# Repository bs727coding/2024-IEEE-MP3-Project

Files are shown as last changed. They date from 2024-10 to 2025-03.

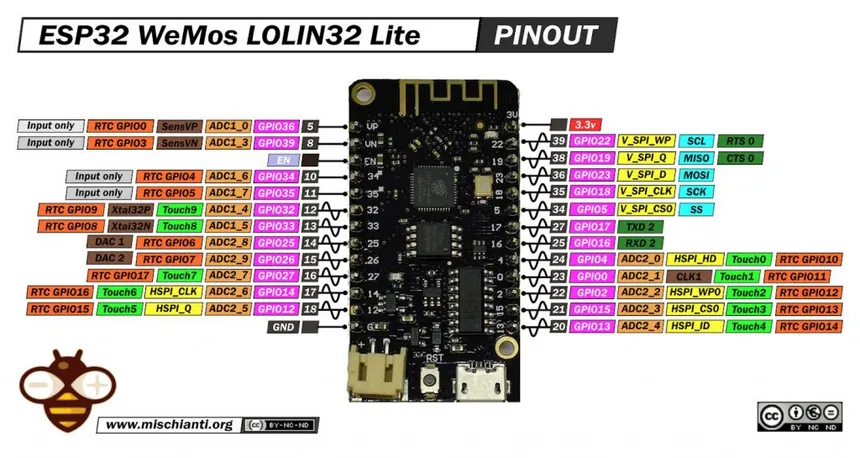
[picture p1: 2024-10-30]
ESP32-WeMos-LOLIN32-Lite-pinout.webp

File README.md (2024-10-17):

# 2024-IEEE-MP3-Project

A simple media player with bluetooth support using an ESP32, LCD display, audio driver, battery, and button controls.

This is a part of the Brigham Young University IEEE student branch 2024-2025 project.

There are 4 outcomes we hope to accomplish with this project. These are:

    Develop an understanding of KiCAD and PCB design, including footprint design, schematic development, and design rules.
    Learn embedded programming by using FreeRTOS and C to program an ESP32 microcontroller to process media files and control its input and output functions.
    Acquire skill in how to use CAD softwares to design an appropriate chassis for electrical components.
    Become confident and consistent in electrical engineering project documentation.

We anticipate this project will be exciting, challenging, and provide participating students an opportunity to grow their engineering skills outside of a classroom setting.

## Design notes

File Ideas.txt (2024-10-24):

What we want to implement:
* designates 1st gen

Sharepoint (cast to Chromecast, Apple airplay, ect.)
*BLDC motor/encoder (selection/volume control)
*SD card (storage)
Emulate USB Mass Storage
*Screen - 2-3 inches, full color
Video?
No internal speaker
Charge circuitry integrated MCU
LiPo or Lion
*IO Buttons: 4
*Single pole triple throw power switch: Off, On, Playback(on but buttons disabled)
Brightness control (possibly via POT and not through ESP32)
Battery indicator (Neopixel)
SOC?
*TRS port (headphone jack, with plugin/unplug detection)

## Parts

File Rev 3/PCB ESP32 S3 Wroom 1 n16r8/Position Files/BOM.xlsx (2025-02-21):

Comment | Designator | Footprint | JLCPCB Part #（optional）
15uh | L1 | Inductor_SMD:L_Vishay_IFSC-1515AH_4x4x1.8mm | C844950
.1uF | C1 | Capacitor_SMD:C_0201_0603Metric | C1591
2.2uF | C2 | Capacitor_SMD:C_0201_0603Metric | C86013
10uf | C3 | Capacitor_SMD:C_0201_0603Metric | C1691
69.8k | R14 | Resistor_SMD:R_01005_0402Metric | C26985
22.1k | R15 | Resistor_SMD:R_01005_0402Metric | C102896
LMR54410DBVR | U1 | LMR54410DBVR:SOT95P280X145-6N | C3200265
ESP 32 S3 Wroom N16R8 | X1 | ESP32-S3-WROOM-1-N16R8 | C2913202

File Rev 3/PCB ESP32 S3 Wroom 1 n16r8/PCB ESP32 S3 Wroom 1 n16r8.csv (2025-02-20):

Id | Designator | Footprint | Quantity | Designation | Supplier and ref
1 | SW1 | Kailh_socket_PG1350 | 1 | Home
2 | J1 | Jack_3.5mm_CUI_SJ1-3524N_Horizontal | 1 | AudioJack3_SwitchT
3 | R4,R1,R2,R3,R6,R5,R13,R8,R11,R9,R10 | R_Axial_DIN0204_L3.6mm_D1.6mm_P7.62mm_Horizontal | 11 | 10K
4 | SW2 | Kailh_socket_PG1350 | 1 | Back
5 | Primary Rotary Encoder1 | RotaryEncoder_Alps_EC11E-Switch_Vertical_H20mm | 1 | RotaryEncoder_Switch
6 | L_SPKR1,RSPKR1 | MAX98357 I2C Audio Driver | 2 | ~
7 | SW5 | Kailh_socket_PG1350 | 1 | Menu
8 | Screen&SDCardReader1 | 2.4'_TFT_SPI_ILI9341_WITH_SD_CARD | 1 | ~
9 | SW3 | Kailh_socket_PG1350 | 1 | Play/Pause
10 | D1 | D_A-405_P7.62mm_Horizontal | 1 | Flyback Diode
11 | M1 | TerminalBlock_RND_205-00001_1x02_P5.00mm_Horizontal | 1 | Haptic Feedback
12 | R12 | R_Axial_DIN0204_L3.6mm_D1.6mm_P7.62mm_Horizontal | 1 | 100K
13 | C1 | C_0201_0603Metric | 1 | .1 uF
14 | SW6 | SW_Slide_SPDT_Angled_CK_OS102011MA1Q | 1 | Hold
15 | L1 | L_Vishay_IFSC-1515AH_4x4x1.8mm | 1 | 15uH
16 | X1 | ESP32S3WROOM1N8R2 | 1 | ESP32-S3-WROOM-1-N16R8
17 | SW4 | SW_Slide_SPDT_Angled_CK_OS102011MA1Q | 1 | Power
18 | R14 | R_01005_0402Metric | 1 | 69.8K
19 | SW7 | SW_PUSH_6mm | 1 | BOOT_MODE
20 | C3 | C_0201_0603Metric | 1 | 10uF
21 | Q1 | TO-92_Inline | 1 | BS170
22 | C2 | C_0201_0603Metric | 1 | 2.2 uF
23 | U1 | SOT95P280X145-6N | 1 | LMR54410DBVR
24 | R7 | R_Axial_DIN0204_L3.6mm_D1.6mm_P7.62mm_Horizontal | 1 | 0-100Ω
25 | R15 | R_01005_0402Metric | 1 | 22.1K
26 | 1 | UART_FTDI | 1 | ~

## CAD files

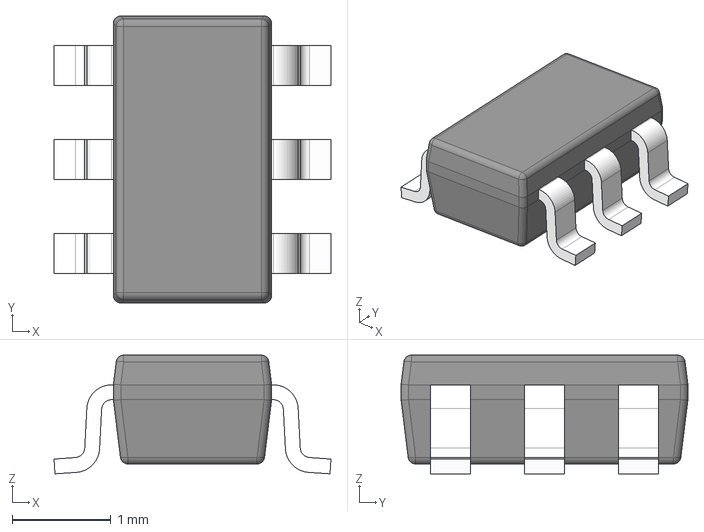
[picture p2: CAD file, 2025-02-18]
Rev 3/PCB ESP32 S3 Wroom 1 n16r8/LMR54410DBVR/LMR54410DBVR.stp
2.80 x 2.90 x 1.20 mm
BODY-SOT
LEAD-SOT x 6

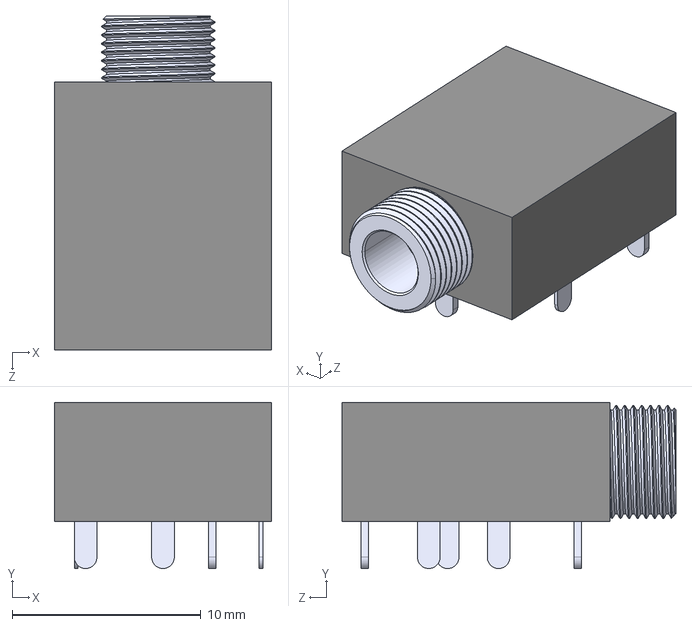
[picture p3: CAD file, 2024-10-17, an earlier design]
Rev 1/Custom Footprints/PJ324M/PJ324M.step
11.5 x 8.80 x 17.7 mm

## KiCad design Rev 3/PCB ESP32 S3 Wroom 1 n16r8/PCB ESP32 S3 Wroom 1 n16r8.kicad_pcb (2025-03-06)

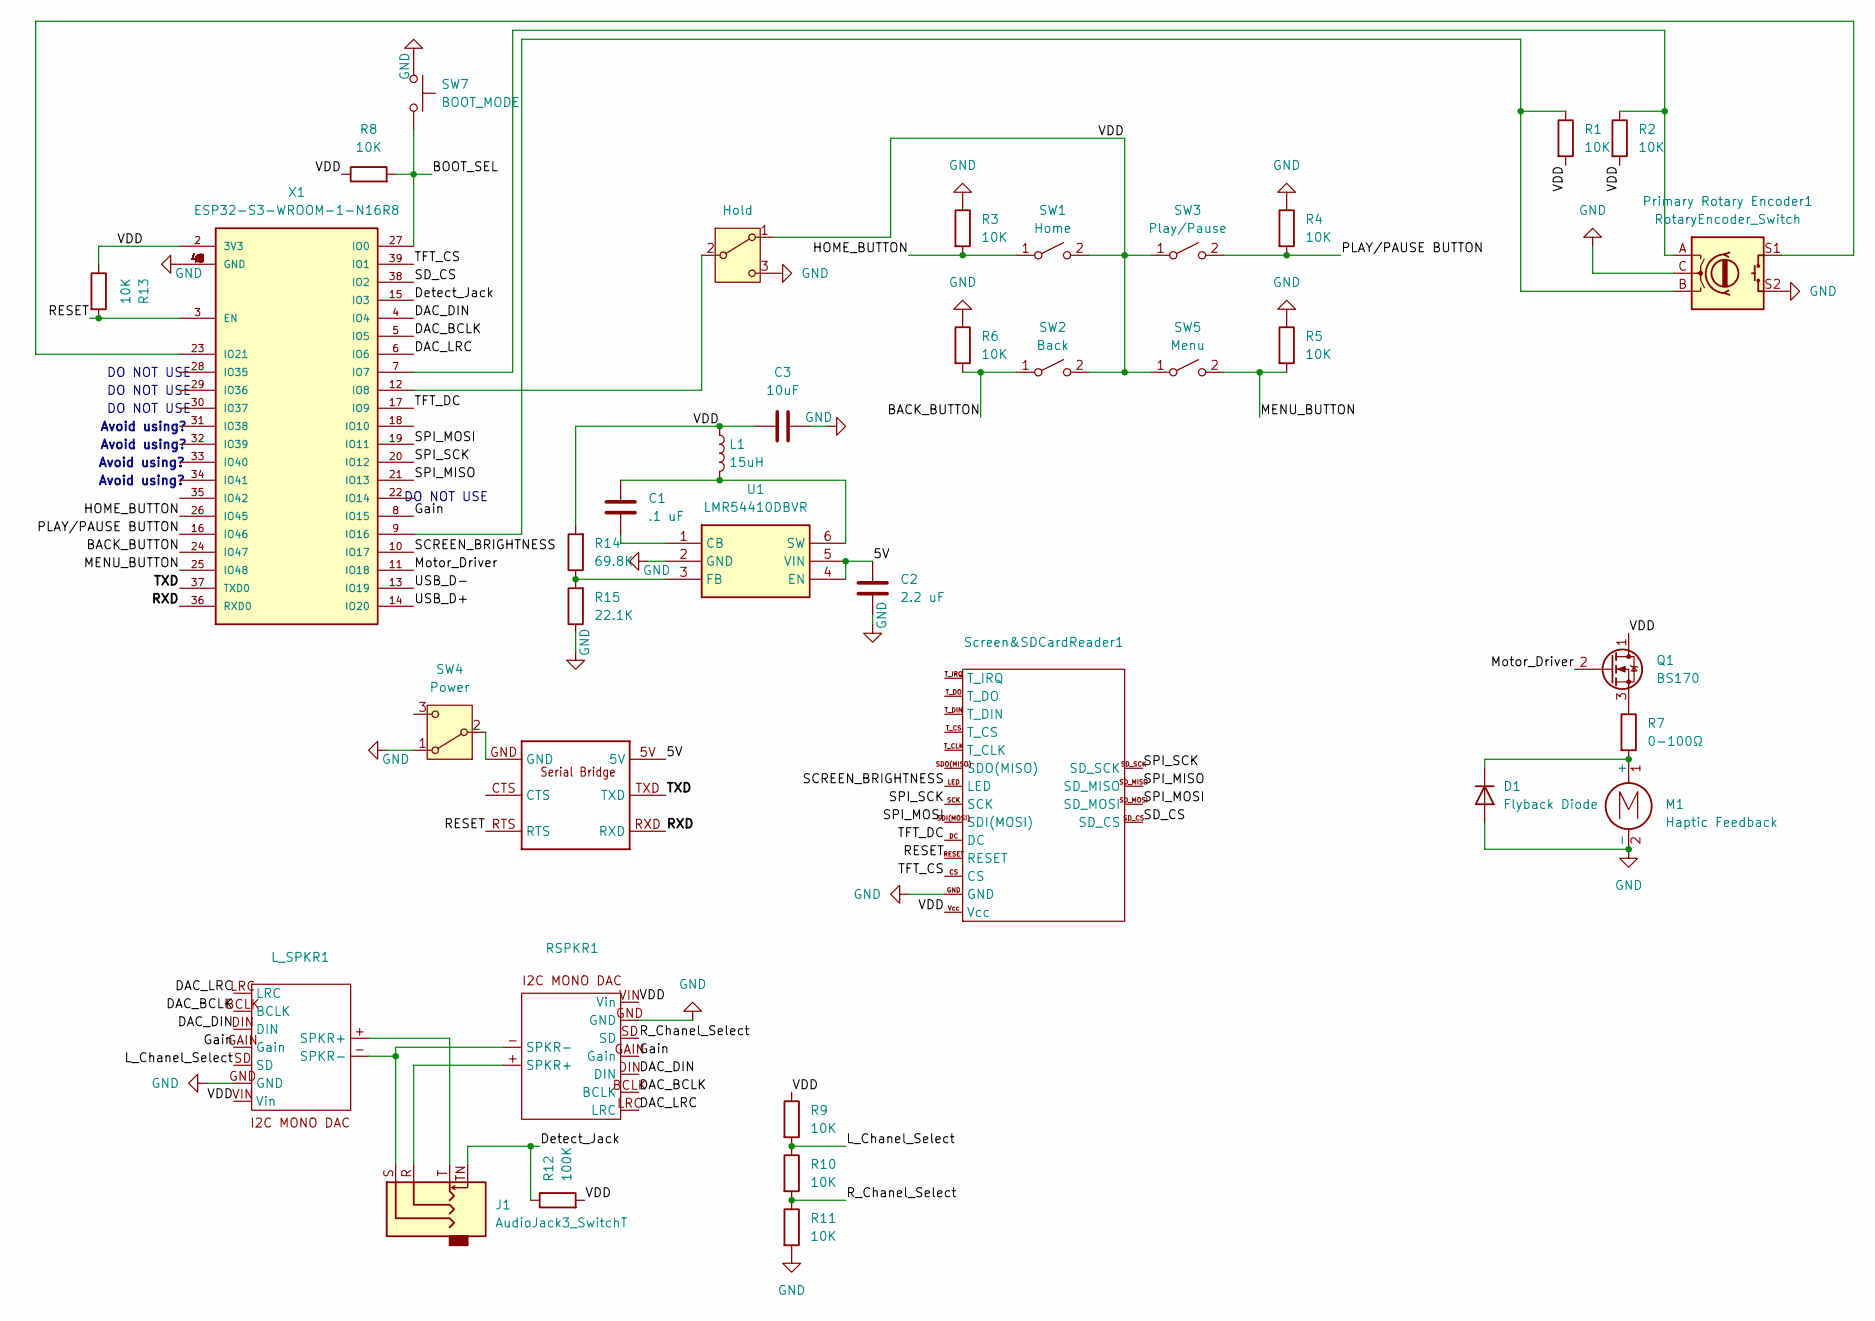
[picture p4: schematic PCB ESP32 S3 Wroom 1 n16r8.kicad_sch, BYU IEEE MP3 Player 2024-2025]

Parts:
1: UART_FTDI
C1: .1 uF; C_0603_1608Metric
C2: 2.2 uF; C_0603_1608Metric
C3: 10uF; C_0603_1608Metric
D1: Flyback Diode; D_A-405_P7.62mm_Horizontal
J1: AudioJack3_SwitchT; Jack_3.5mm_CUI_SJ1-3524N_Horizontal
L1: 15uH; L_Vishay_IFSC-1515AH_4x4x1.8mm
L_SPKR1: MAX98357 I2C Audio Driver
M1: Haptic Feedback; TerminalBlock_RND_205-00001_1x02_P5.00mm_Horizontal
Primary Rotary Encoder1: RotaryEncoder_Switch; RotaryEncoder_Alps_EC11E-Switch_Vertical_H20mm
Q1: BS170; TO-92_Inline
R1, R2, R3, R4, R5, R6, R8, R9, R10, R11, R13: 10K; R_Axial_DIN0204_L3.6mm_D1.6mm_P7.62mm_Horizontal
R7: 0-100Ω; R_Axial_DIN0204_L3.6mm_D1.6mm_P7.62mm_Horizontal
R12: 100K; R_Axial_DIN0204_L3.6mm_D1.6mm_P7.62mm_Horizontal
R14: 69.8K; R_01005_0402Metric_Pad0.57x0.30mm_HandSolder
R15: 22.1K; R_01005_0402Metric_Pad0.57x0.30mm_HandSolder
RSPKR1: MAX98357 I2C Audio Driver
SW1: Home; Kailh_socket_PG1350
SW2: Back; Kailh_socket_PG1350
SW3: Play/Pause; Kailh_socket_PG1350
SW4: Power; SW_Slide_SPDT_Angled_CK_OS102011MA1Q
SW5: Menu; Kailh_socket_PG1350
SW6: Hold; SW_Slide_SPDT_Angled_CK_OS102011MA1Q
SW7: BOOT_MODE; SW_PUSH_6mm
Screen&SDCardReader1: 2.4'_TFT_SPI_ILI9341_WITH_SD_CARD
U1: LMR54410DBVR; SOT95P280X145-6N; Mouser Part Number 595-LMR54410DBVR
X1: ESP32-S3-WROOM-1-N16R8; ESP32S3WROOM1N8R2; MANUFACTURER_PART_NUMBER ESP32-S3-WROOM-1-N16R8

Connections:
/5V: 1.5V, C2.2, U1.4 (EN), U1.5 (VIN)
/BACK_BUTTON: R6.2, SW2.1 (A), X1.24 (IO47)
/BOOT_SEL: R8.2, SW7.2, X1.27 (IO0)
/DAC_BCLK: L_SPKR1.BCLK, RSPKR1.BCLK, X1.5 (IO5)
/DAC_DIN: L_SPKR1.DIN, RSPKR1.DIN, X1.4 (IO4)
/DAC_LRC: L_SPKR1.LRC, RSPKR1.LRC, X1.6 (IO6)
/Detect_Jack: J1.TN, R12.1, X1.15 (IO3)
/Gain: L_SPKR1.GAIN (Gain), RSPKR1.GAIN (Gain), X1.8 (IO15)
/HOME_BUTTON: R3.2, SW1.1 (A), X1.26 (IO45)
/L_Chanel_Select: L_SPKR1.SD, R9.2, R10.1
/MENU_BUTTON: R5.2, SW5.2 (B), X1.25 (IO48)
/Motor_Driver: Q1.2 (G), X1.11 (IO18)
/PLAY/PAUSE BUTTON: R4.2, SW3.2 (B), X1.16 (IO46)
/RESET: 1.RTS, R13.2, Screen&SDCardReader1.RESET, X1.3 (EN)
/RXD: 1.RXD, X1.36 (RXD0)
/R_Chanel_Select: R10.2, R11.1, RSPKR1.SD
/SCREEN_BRIGHTNESS: Screen&SDCardReader1.LED, X1.10 (IO17)
/SD_CS: Screen&SDCardReader1.SD_CS, X1.38 (IO2)
/SPI_MISO: Screen&SDCardReader1.SD_MISO, X1.21 (IO13)
/SPI_MOSI: Screen&SDCardReader1.SDI(MOSI), Screen&SDCardReader1.SD_MOSI, X1.19 (IO11)
/SPI_SCK: Screen&SDCardReader1.SCK, Screen&SDCardReader1.SD_SCK, X1.20 (IO12)
/TFT_CS: Screen&SDCardReader1.CS, X1.39 (IO1)
/TFT_DC: Screen&SDCardReader1.DC, X1.17 (IO9)
/TXD: 1.TXD, X1.37 (TXD0)
/USB_D+: X1.14 (IO20)
/USB_D-: X1.13 (IO19)
/VDD: C3.2, L1.1, L_SPKR1.VIN (Vin), Q1.1 (D), R1.2, R2.2, R8.1, R9.1, R12.2, R13.1, R14.2, RSPKR1.VIN (Vin), SW1.2 (B), SW2.2 (B), SW3.1 (A), SW5.1 (A), SW6.1 (A), Screen&SDCardReader1.Vcc, X1.2 (3V3)
GND: C2.1, C3.1, D1.2 (A), L_SPKR1.GND, M1.2 (-), Primary Rotary Encoder1.C, Primary Rotary Encoder1.S2, R3.1, R4.1, R5.1, R6.1, R11.2, R15.1, RSPKR1.GND, SW4.1 (A), SW6.3 (C), SW7.1, Screen&SDCardReader1.GND, U1.2 (GND), X1.1 (GND), X1.40 (GND), X1.41 (GND), X1.42 (GND), X1.43 (GND), X1.44 (GND), X1.45 (GND), X1.46 (GND), X1.47 (GND), X1.48 (GND), X1.49 (GND)
unnamed: D1.1 (K), M1.1 (+), R7.2
unnamed: J1.T, L_SPKR1.+ (SPKR+)
unnamed: J1.S, L_SPKR1.- (SPKR-), RSPKR1.- (SPKR-)
unnamed: Q1.3 (S), R7.1
unnamed: J1.R, RSPKR1.+ (SPKR+)
unnamed: 1.GND, SW4.2 (B)
unnamed: SW6.2 (B), X1.12 (IO8)
unnamed: C1.2, U1.1 (CB)
unnamed: R14.1, R15.2, U1.3 (FB)
unnamed: C1.1, L1.2, U1.6 (SW)
unnamed: Primary Rotary Encoder1.A, R2.1, X1.7 (IO7)
unnamed: Primary Rotary Encoder1.B, R1.1, X1.9 (IO16)
unnamed: Primary Rotary Encoder1.S1, X1.23 (IO21)

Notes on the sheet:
Avoid using?
DO NOT USE

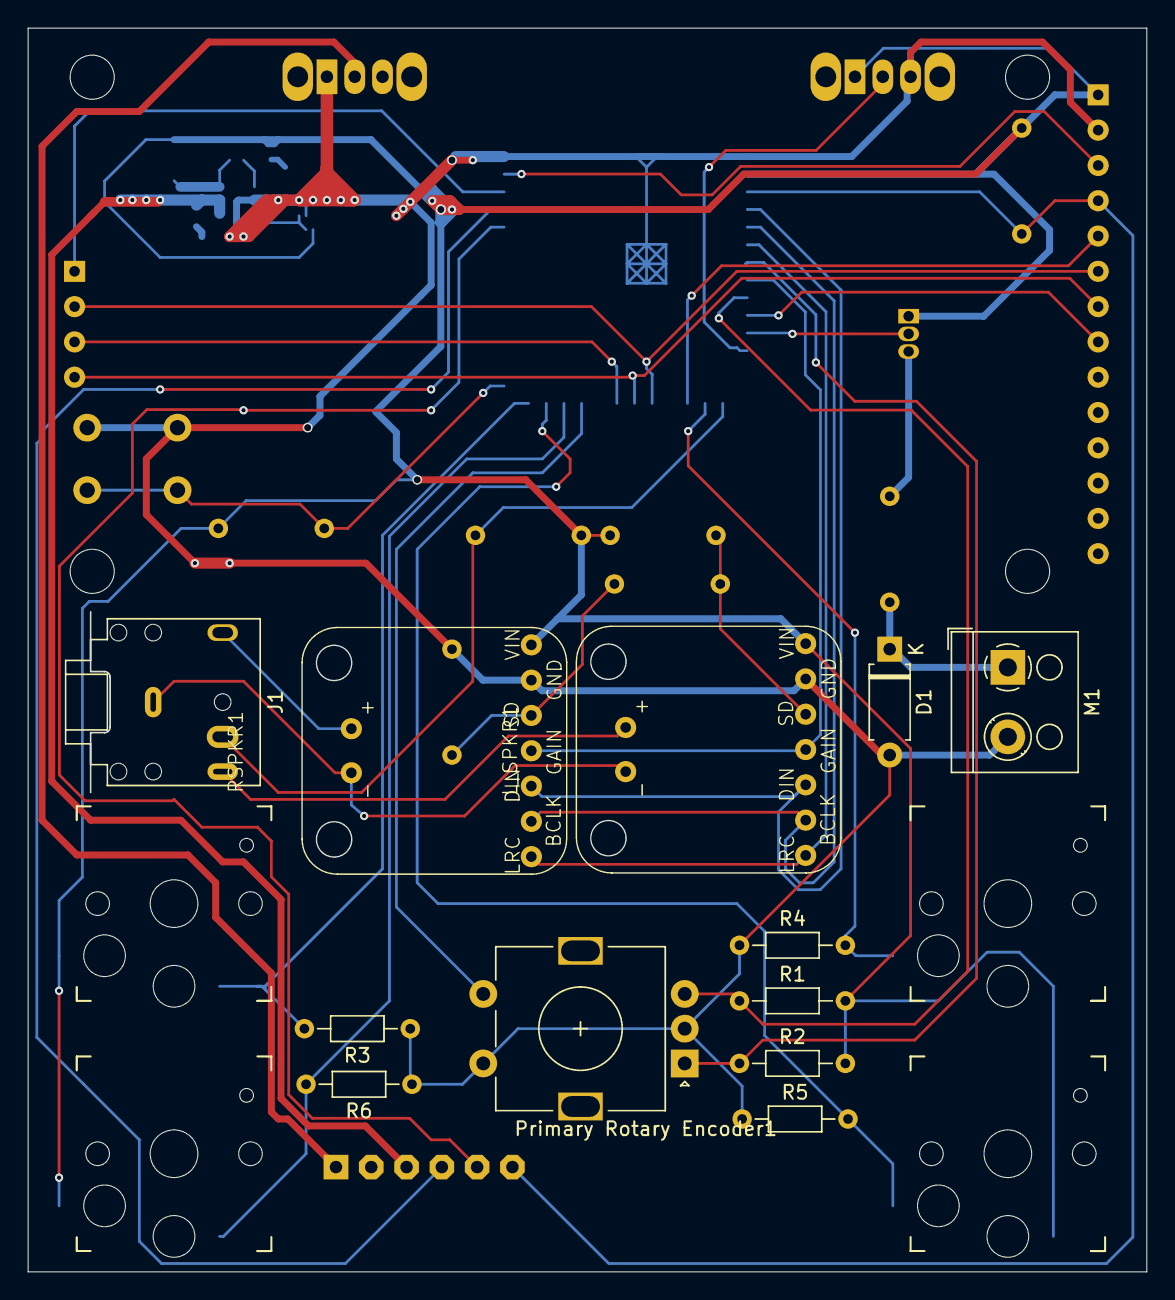
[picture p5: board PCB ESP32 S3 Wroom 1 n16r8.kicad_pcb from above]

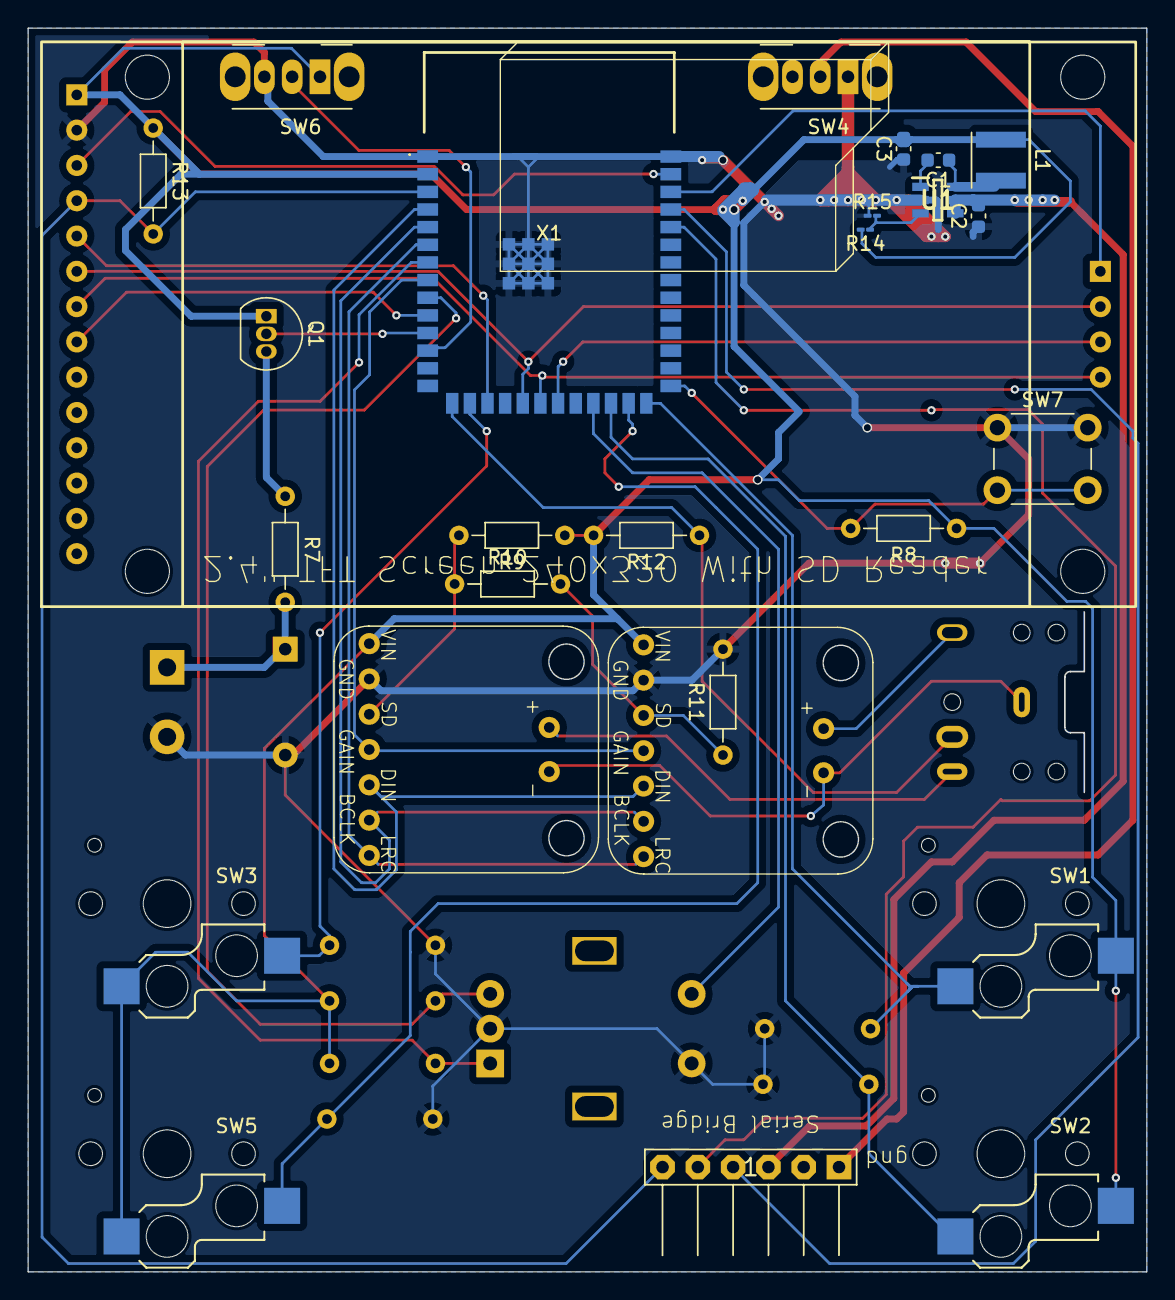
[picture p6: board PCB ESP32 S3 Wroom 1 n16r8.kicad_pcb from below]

Board: 2 copper layers, 80.5 x 89.5 mm, 37 parts (20 on the bottom side), 39 nets.

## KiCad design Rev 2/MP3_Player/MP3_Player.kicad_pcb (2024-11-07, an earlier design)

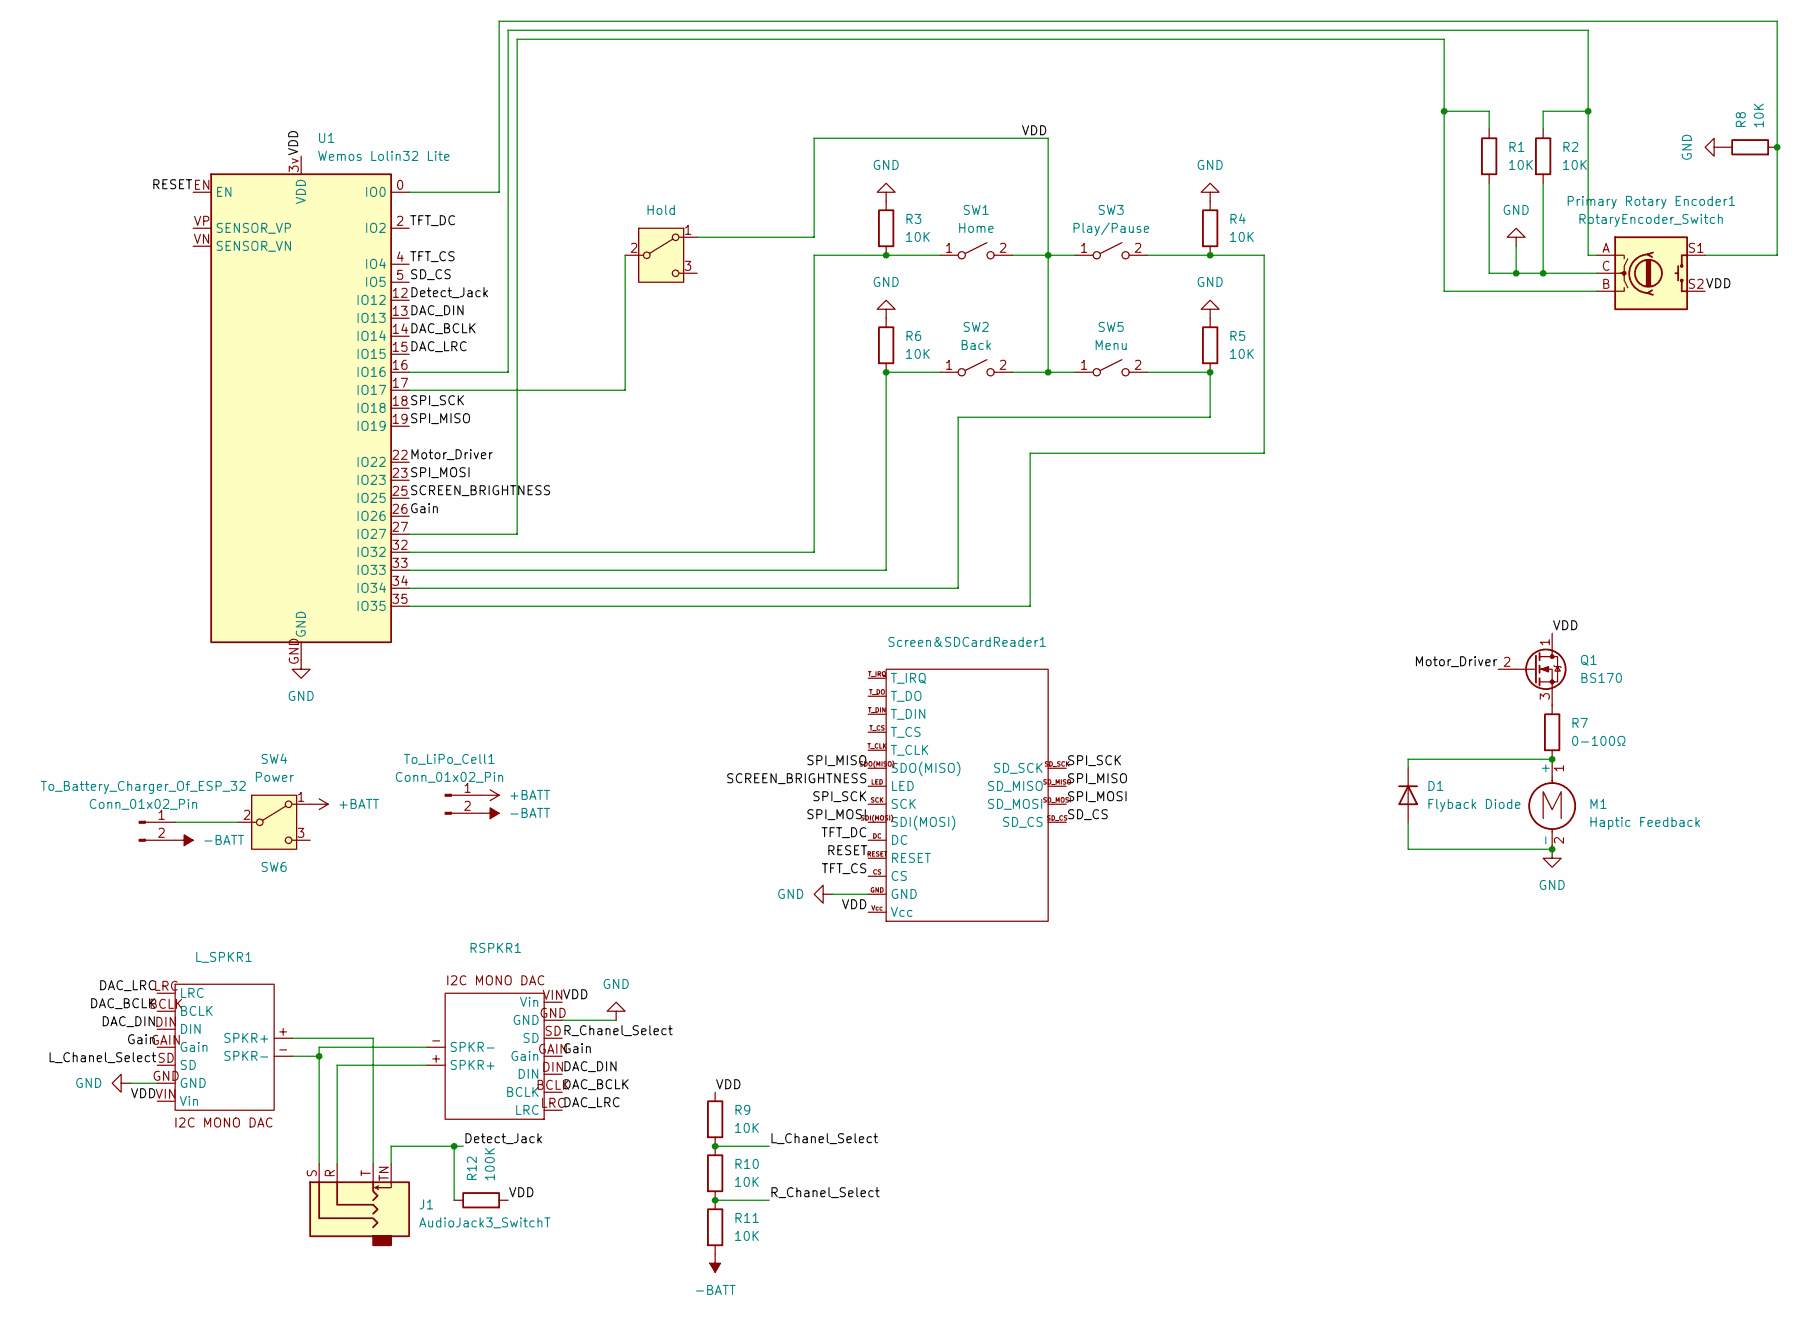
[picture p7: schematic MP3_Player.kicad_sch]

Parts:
D1: Flyback Diode; D_A-405_P7.62mm_Horizontal
J1: AudioJack3_SwitchT; Jack_3.5mm_CUI_SJ1-3524N_Horizontal
L_SPKR1: MAX98357 I2C Audio Driver
M1: Haptic Feedback; TerminalBlock_RND_205-00001_1x02_P5.00mm_Horizontal
Primary Rotary Encoder1: RotaryEncoder_Switch; RotaryEncoder_Alps_EC11E-Switch_Vertical_H20mm
Q1: BS170; TO-92_Inline
R1, R2, R3, R4, R5, R6, R8, R9, R10, R11: 10K; R_Axial_DIN0204_L3.6mm_D1.6mm_P7.62mm_Horizontal
R7: 0-100Ω; R_Axial_DIN0204_L3.6mm_D1.6mm_P7.62mm_Horizontal
R12: 100K; R_Axial_DIN0204_L3.6mm_D1.6mm_P7.62mm_Horizontal
RSPKR1: MAX98357 I2C Audio Driver
SW1: Home; Kailh_socket_PG1350
SW2: Back; Kailh_socket_PG1350
SW3: Play/Pause; Kailh_socket_PG1350
SW4: Power; SW_Slide_SPDT_Angled_CK_OS102011MA1Q
SW5: Menu; Kailh_socket_PG1350
SW6: Hold; SW_Slide_SPDT_Angled_CK_OS102011MA1Q
Screen&SDCardReader1: 2.4'_TFT_SPI_ILI9341_WITH_SD_CARD
To_Battery_Charger_Of_ESP_32: Conn_01x02_Pin; JST_XA_B02B-XASK-1-A_1x02_P2.50mm_Vertical
To_LiPo_Cell1: Conn_01x02_Pin; JST_XA_B02B-XASK-1-A_1x02_P2.50mm_Vertical
U1: Wemos Lolin32 Lite; Wemos Lolin32 Lite v1.0.0

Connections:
+BATT: SW4.1 (A), To_LiPo_Cell1.1
-BATT: R11.2, To_Battery_Charger_Of_ESP_32.2, To_LiPo_Cell1.2
/DAC_BCLK: L_SPKR1.BCLK, RSPKR1.BCLK, U1.14 (IO14)
/DAC_DIN: L_SPKR1.DIN, RSPKR1.DIN, U1.13 (IO13)
/DAC_LRC: L_SPKR1.LRC, RSPKR1.LRC, U1.15 (IO15)
/Detect_Jack: J1.TN, R12.1, U1.12 (IO12)
/Gain: L_SPKR1.GAIN (Gain), RSPKR1.GAIN (Gain), U1.26 (IO26)
/L_Chanel_Select: L_SPKR1.SD, R9.2, R10.1
/Motor_Driver: Q1.2 (G), U1.22 (IO22)
/RESET: Screen&SDCardReader1.RESET, U1.EN
/R_Chanel_Select: R10.2, R11.1, RSPKR1.SD
/SCREEN_BRIGHTNESS: Screen&SDCardReader1.LED, U1.25 (IO25)
/SD_CS: Screen&SDCardReader1.SD_CS, U1.5 (IO5)
/SPI_MISO: Screen&SDCardReader1.SDO(MISO), Screen&SDCardReader1.SD_MISO, U1.19 (IO19)
/SPI_MOSI: Screen&SDCardReader1.SDI(MOSI), Screen&SDCardReader1.SD_MOSI, U1.23 (IO23)
/SPI_SCK: Screen&SDCardReader1.SCK, Screen&SDCardReader1.SD_SCK, U1.18 (IO18)
/TFT_CS: Screen&SDCardReader1.CS, U1.4 (IO4)
/TFT_DC: Screen&SDCardReader1.DC, U1.2 (IO2)
/VDD: L_SPKR1.VIN (Vin), Primary Rotary Encoder1.S2, Q1.1 (D), R9.1, R12.2, RSPKR1.VIN (Vin), SW1.2 (B), SW2.2 (B), SW3.1 (A), SW5.1 (A), SW6.1 (A), Screen&SDCardReader1.Vcc, U1.3v (VDD)
GND: D1.2 (A), L_SPKR1.GND, M1.2 (-), Primary Rotary Encoder1.C, R1.2, R2.2, R3.1, R4.1, R5.1, R6.1, R8.1, RSPKR1.GND, Screen&SDCardReader1.GND, U1.GND
unnamed: D1.1 (K), M1.1 (+), R7.2
unnamed: J1.T, L_SPKR1.+ (SPKR+)
unnamed: J1.S, L_SPKR1.- (SPKR-), RSPKR1.- (SPKR-)
unnamed: Q1.3 (S), R7.1
unnamed: J1.R, RSPKR1.+ (SPKR+)
unnamed: R3.2, SW1.1 (A), U1.32 (IO32)
unnamed: R6.2, SW2.1 (A), U1.33 (IO33)
unnamed: R4.2, SW3.2 (B), U1.35 (IO35)
unnamed: SW4.2 (B), To_Battery_Charger_Of_ESP_32.1
unnamed: R5.2, SW5.2 (B), U1.34 (IO34)
unnamed: SW6.2 (B), U1.17 (IO17)
unnamed: Primary Rotary Encoder1.S1, R8.2, U1.0 (IO0)
unnamed: Primary Rotary Encoder1.A, R2.1, U1.16 (IO16)
unnamed: Primary Rotary Encoder1.B, R1.1, U1.27 (IO27)

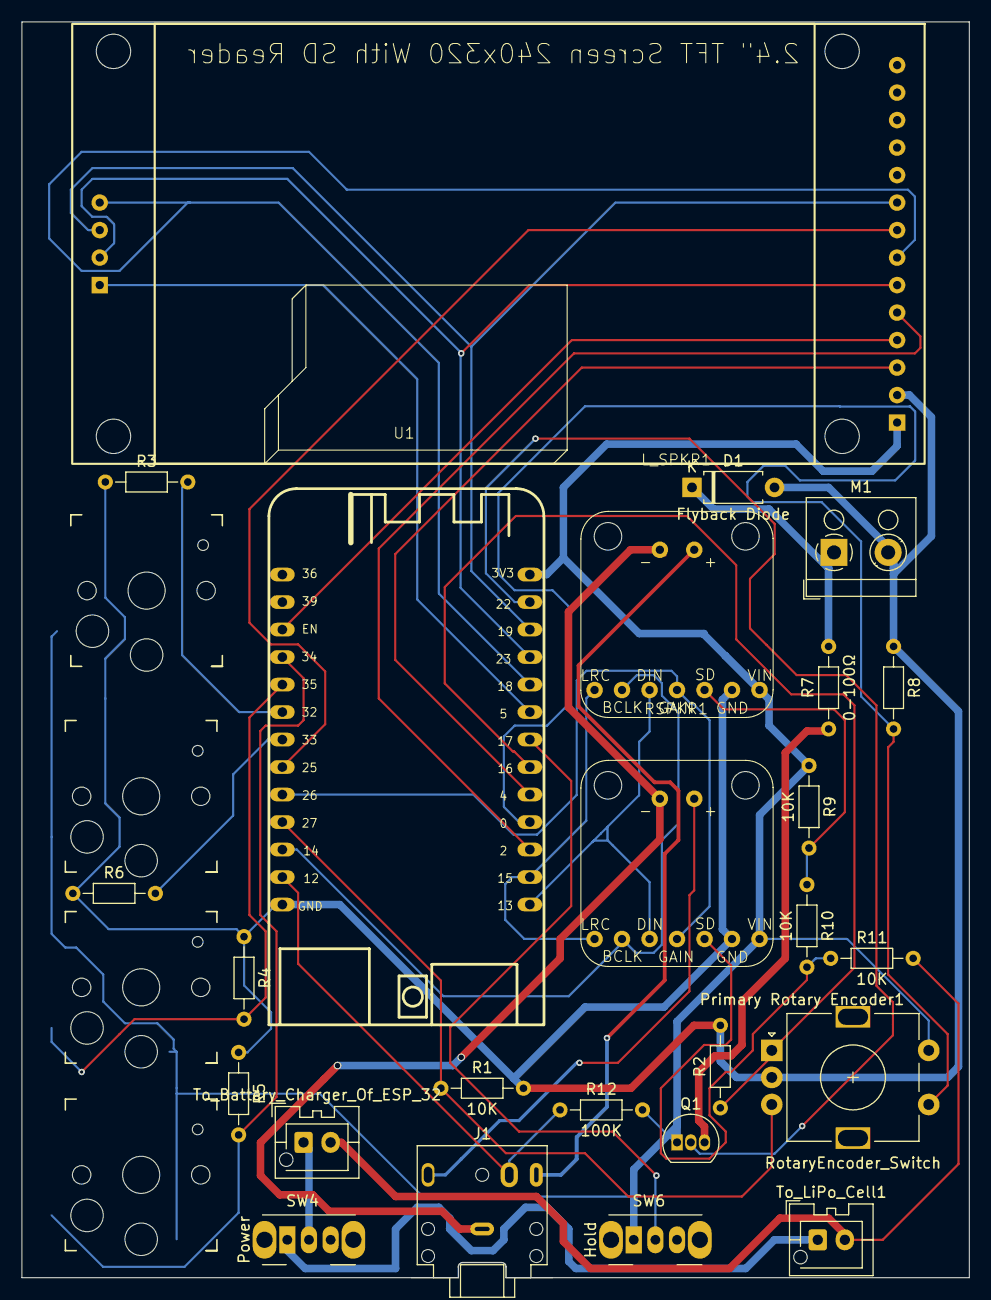
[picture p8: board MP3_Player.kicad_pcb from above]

Board: 2 copper layers, 87.5 x 116.0 mm, 29 parts (1 on the bottom side), 34 nets.

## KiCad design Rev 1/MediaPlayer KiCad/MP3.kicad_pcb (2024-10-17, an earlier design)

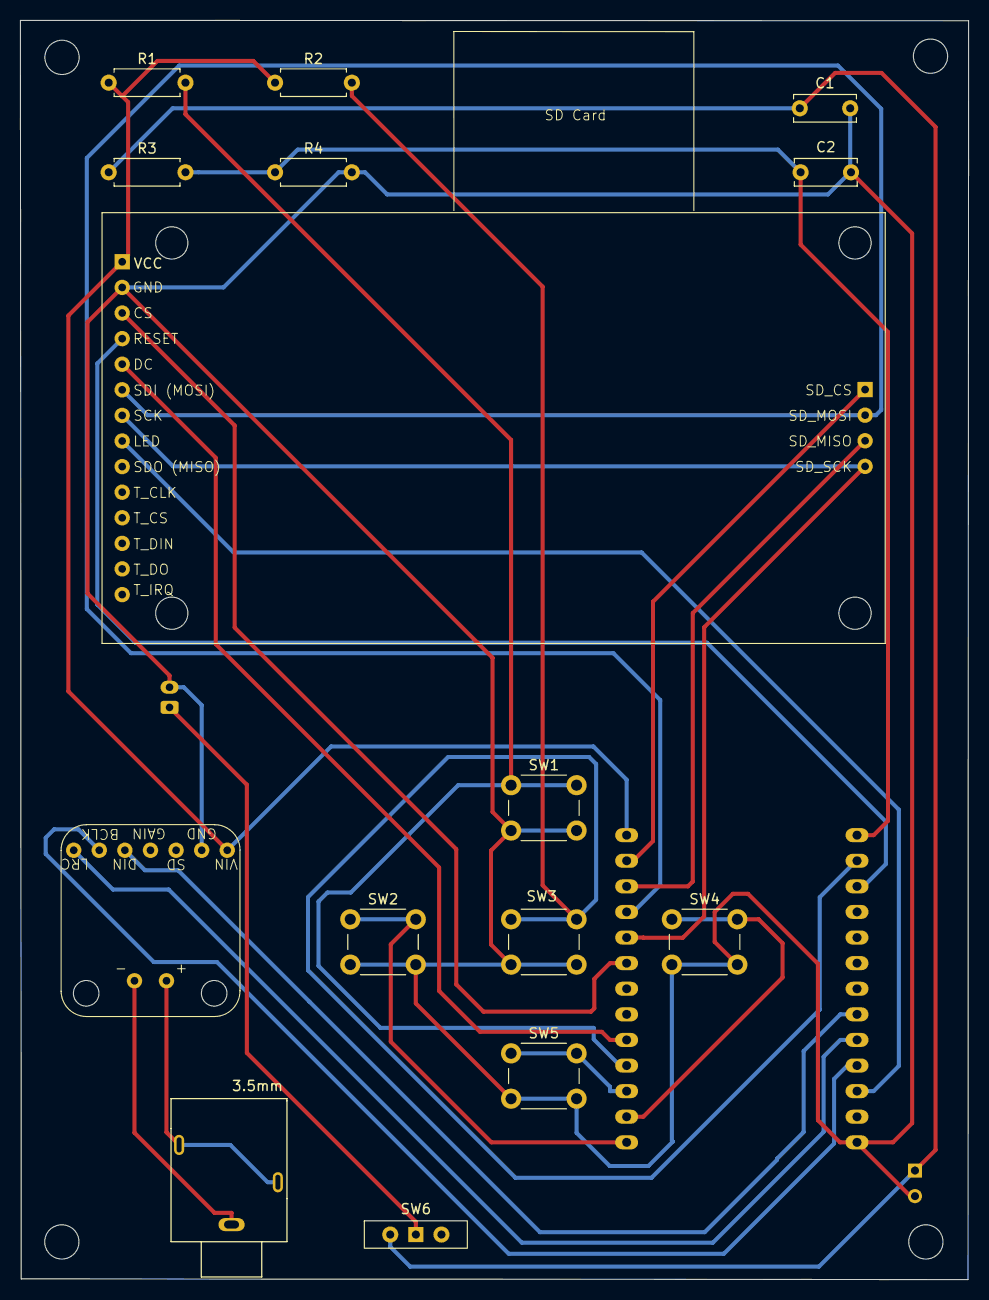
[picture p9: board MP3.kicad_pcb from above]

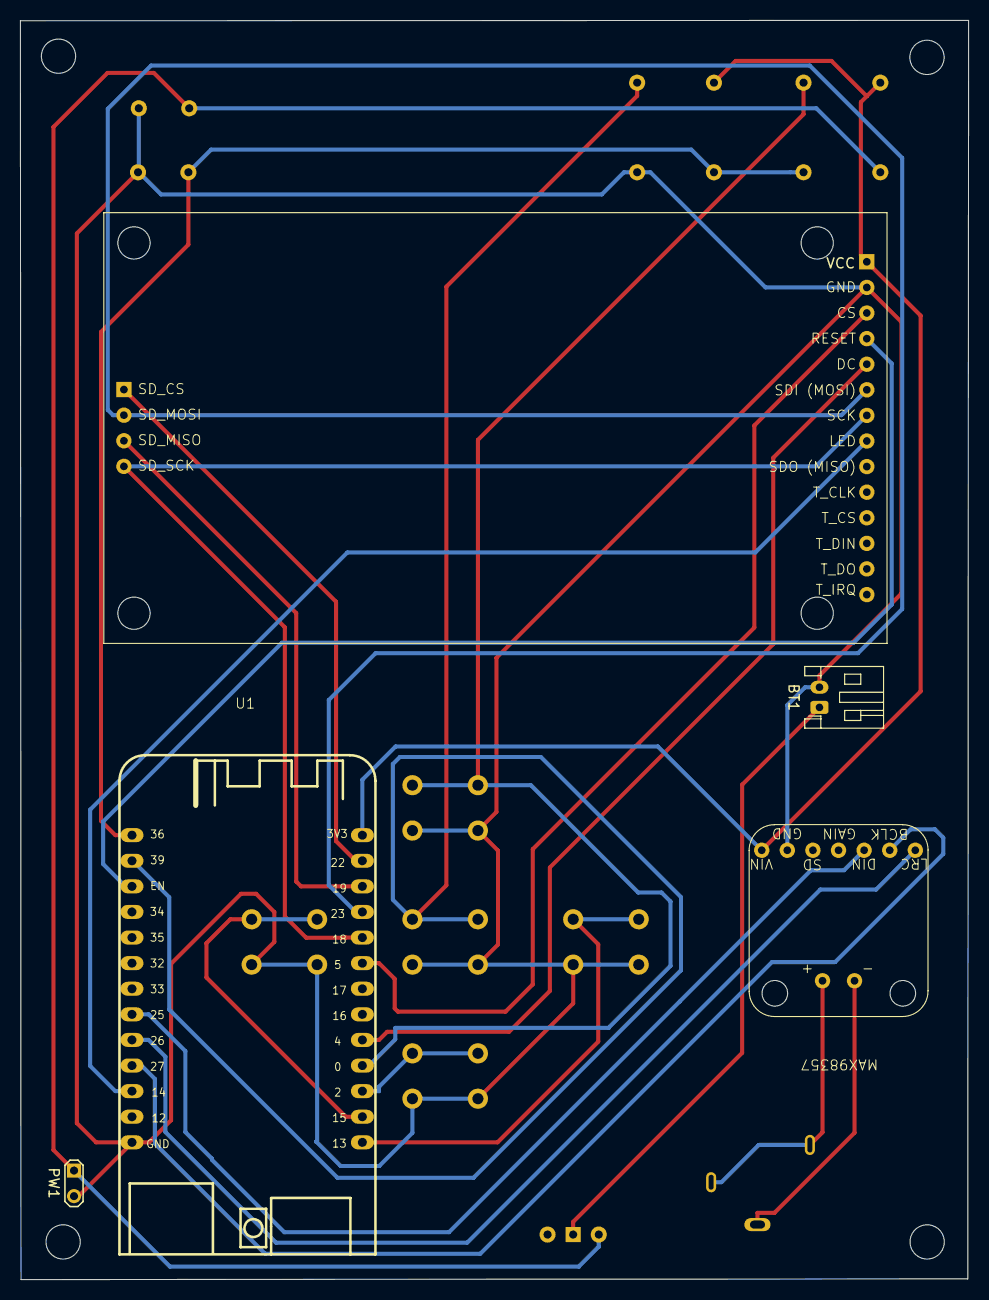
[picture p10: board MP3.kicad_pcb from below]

Board: 2 copper layers, 94.1 x 125.0 mm, 17 parts (4 on the bottom side), 15 nets.

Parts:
3.5mm: WENZHOU_PJ324M_2
BT1: JST_PH_S2B-PH-K_1x02_P2.00mm_Horizontal
C1: C1; C_Disc_D6.0mm_W2.5mm_P5.00mm
C2: C2; C_Disc_D6.0mm_W2.5mm_P5.00mm
MAX98357: MAX98357 I2C Audio Driver
PW1: TestPoint_2Pads_Pitch2.54mm_Drill0.8mm
R1: R1; R_Axial_DIN0207_L6.3mm_D2.5mm_P7.62mm_Horizontal
R2: R2; R_Axial_DIN0207_L6.3mm_D2.5mm_P7.62mm_Horizontal
R3: R3; R_Axial_DIN0207_L6.3mm_D2.5mm_P7.62mm_Horizontal
R4: R4; R_Axial_DIN0207_L6.3mm_D2.5mm_P7.62mm_Horizontal
SW1, SW2, SW3, SW4, SW5: SW_PUSH_6mm
SW6: SW_Slide-03_Wuerth-WS-SLTV_10x2.5x6.4_P2.54mm
U1: Wemos Lolin32 Lite v1.0.0

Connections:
GND: BT1.2, C1.2, C2.2, MAX98357.GND, PW1.1, R4.2, SW1.2, SW2.2, SW3.2, SW4.2, SW5.2, U1.GND
MAX_BCLK: MAX98357.BCLK, U1.27
MAX_DIN: MAX98357.DIN, U1.25
MAX_LRC: MAX98357.LRC, U1.26
PWR: BT1.1, SW6.1
SW1: R1.2, SW1.1, U1.0
SW2: SW2.1, U1.13
SW3: R2.2, SW3.1, U1.VN
SW4: SW4.1, U1.15
SW5: SW5.1, U1.2
VCC: MAX98357.VIN, R1.1, R2.1, U1.3v
VCC2: C1.1, PW1.2, R3.1, SW6.2
VP: C2.1, R3.2, R4.1, U1.VP
audio+: 3.5mm.2 (R), 3.5mm.5 (L), MAX98357.+
audio-: 3.5mm.1 (GND), MAX98357.-

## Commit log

2024-10-17 Added KiCad project files and readme.md file
    [MP3-B_Cu.gbr, MP3-B_Mask.gbr, MP3-B_Paste.gbr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]
2024-10-24 Test, moved around files
    [MP3-B_Cu.gbr, MP3-B_Mask.gbr, MP3-B_Paste.gbr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]
2024-10-24 Rev 2 upload
    [MP3_Player.kicad_pcb, MP3_Player.kicad_sch]
2024-10-24 added esp32
    [MP3_Player.kicad_sch]
2024-10-24 added some parts
    [MP3_Player.kicad_sch]
2024-10-24 Finished Setup
    [MP3_Player.kicad_sch]
2024-10-26 W/ Wired Rotary Encoder
    [MP3_Player.kicad_sch]
2024-10-28 fixed some save bugs
    [MP3_Player-Natos-3080.kicad_sch]
2024-10-29 W/ Wired Rotary Encoder Switches & Keys
    [MP3_Player.kicad_sch]
2024-10-29 Added pullup on the buttons
    And also a pulldown resistor on the rotary encoder
    [MP3_Player.kicad_sch]
2024-10-30 Finished Wiring
    Edits:
    -Added I2S interface for headphones.
    *Chanel select is dependent on voltage on pin SD
    *Gain is hooked up to ESP32 onboard DAC
    *Detect Pin is added to know if headphones are plugged in/unplugged
    -Moved Pins around for our specific pinout.
    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
    [MP3_Player.kicad_sch]
2024-10-30 Fixed pinout
    -Edited ESP32 pinout so that it links correctly with the provided footprint
    -Re-routed some affected pins
    -Added correct pinout image
    [MP3_Player.kicad_sch]
2024-10-30 Fixed Power Switch
    -Fixed Wiring so power switch is interrupting the battery on its way to the battery charger
    -Fixed Footprint linking issues
    [MP3_Player.kicad_sch]
2024-10-31 Layed out PCB
    [MP3_Player.kicad_pcb]
2024-10-31 wired power and ground
    [MP3_Player.kicad_pcb]
2024-10-31 Fixed Track width of ground to screen
    [MP3_Player.kicad_pcb]
2024-10-31 Imported ECE Shop DRC
    -Imported DRC so we have the option open to print at the shop
    -Fixed one trace that was close to a drill hole
    [Design_Rules_Project.kicad_pcb, Design_Rules_Project.kicad_sch, MP3_Player.kicad_pcb]
2024-11-01 Added Flyback Diode
    -Added Flyback Diode to prevent sparking and unwanted behavior
    -Finished high power rails
    -Fixed Screen Orientation
    -Fixed Placement of some components
    -Fixed Silkscreen
    [MP3_Player.kicad_pcb, MP3_Player.kicad_sch]
2024-11-02 Almost finished routing traces
    [MP3_Player.kicad_pcb]
2024-11-07 Finished routing PCB
    [MP3_Player-B_Cu.gbr, MP3_Player-B_Mask.gbr, MP3_Player-B_Paste.gbr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]
2024-11-07 created fabrication files
    [MP3_Player-B_Cu.gbr, MP3_Player-B_Mask.gbr, MP3_Player-B_Paste.gbr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]
2025-02-07 began work on rev 3
    [PCB ESP32 S3 Wroom 1 n16r8.kicad_pcb, PCB ESP32 S3 Wroom 1 n16r8.kicad_sch]
2025-02-07 updated margins on esp32
    - to prevent traces under antenna
2025-02-07 wired up ESP32 to the best of my knowledge
    [PCB ESP32 S3 Wroom 1 n16r8.kicad_sch]
2025-02-07 reverted pins for USB
    [PCB ESP32 S3 Wroom 1 n16r8.kicad_sch]
2025-02-07 added datasheet
    [PCB ESP32 S3 Wroom 1 n16r8.kicad_sch]
2025-02-07 updated schematic using datasheet
    - checked documentation on all pins
    - added FTDI header, minus 5V to 3v3 Regulator
    [PCB ESP32 S3 Wroom 1 n16r8.kicad_sch]
2025-02-07 Renamed Sheet
    [PCB ESP32 S3 Wroom 1 n16r8.kicad_sch]
2025-02-07 added Kailh switch 3d model for renders
2025-02-08 Added More 3d Models
    [PCB ESP32 S3 Wroom 1 n16r8.kicad_sch]
2025-02-11 added 3v3 regulator
    [PCB ESP32 S3 Wroom 1 n16r8.kicad_pcb, PCB ESP32 S3 Wroom 1 n16r8.kicad_sch]
2025-02-11 Routed more vias
    [PCB ESP32 S3 Wroom 1 n16r8.kicad_pcb]
2025-02-11 finished traces
    [PCB ESP32 S3 Wroom 1 n16r8.kicad_pcb]
2025-02-11 updated d2 footprint
    -1A, 40 V Schottky rectifier per datasheet
    -package size determined from digikey
    [PCB ESP32 S3 Wroom 1 n16r8.kicad_pcb, PCB ESP32 S3 Wroom 1 n16r8.kicad_sch]
2025-02-11 updated inductor footprint
    to be a standard 2424 (6060 metric) mount for a power rectifier.
    [PCB ESP32 S3 Wroom 1 n16r8.kicad_pcb, PCB ESP32 S3 Wroom 1 n16r8.kicad_sch]
2025-02-18 changed out power regulator
    - JLCPCB part package sizes
    - new chip supports 4.5v-36v so it will work with usb power
    [LMR54410DBVR.stp, PCB ESP32 S3 Wroom 1 n16r8.kicad_pcb, PCB ESP32 S3 Wroom 1 n16r8.kicad_sch]
2025-02-20 updated mfg files
    [PCB ESP32 S3 Wroom 1 n16r8-B_Cu.gbr, PCB ESP32 S3 Wroom 1 n16r8-B_Mask.gbr, PCB ESP32 S3 Wroom 1 n16r8-B_Paste.gbr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]
2025-02-20 updated power regulator circuit
    [BOM.xlsx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]
2025-02-20 fixed a trace
2025-02-21 added esp to BOM
    [BOM.xlsx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]
2025-03-06 updated pcb and fixed footprints
    [PCB ESP32 S3 Wroom 1 n16r8-B_Cu.gbr, PCB ESP32 S3 Wroom 1 n16r8-B_Mask.gbr, PCB ESP32 S3 Wroom 1 n16r8-B_Paste.gbr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]
2025-04-03 changed FileHandler to be OOP
    [BOM.xlsx]
